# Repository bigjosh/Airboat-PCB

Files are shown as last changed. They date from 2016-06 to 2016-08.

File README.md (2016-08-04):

Airboat
=======

Firmware and board files for Dame Products Airboat. More product info here...

http://www.dameproducts.com/

Note that this is a fork of the original EVA V2 design which is available here...

https://github.com/bigjosh/vibe-v2

Changes include....

1. Much smaller form factor.
2. MCU switched to smaller ATTINY25/45/85 device.
3. Battery charge controller switched to smaller MCP73832 device.

User Interface
--------------

###Transit Lockout Mode
Device ships in Transit Lockout Mode to prevent inadvertently turning on while in transit. In this mode, the button is completely disconnected and non-functional. To escape from Transit Lockout Mode into normal operating mode, you must connect the unit to the charger.

You can put the device back into Transit Lockout Mode by holding the button down for longer than 10 seconds. During the countdown, the green LED will briefly flash once per second.

After the countdown expires, the  green LED will fade out to indicate that Transit Lockout Mode has been activated.

Note that putting the device into transit lockout mode will reset the speed settings to their factory default values. Considering that there (currently) is no way to change these settings in a production unit, this is probably a null feature, but could be useful if somehow the settings ever get corrupted in a field unit.  

Note: this mode also protects the unit from over discharging the battery in case the button gets stuck down because something is continuously pressing on it.

###Normal Operating Mode
Device is normally in a low-power off state.

A long button press (~0.25 sec) goes straight to off state from any speed. 

A short button press steps to the next speed setting upon button release. There are 3 speed settings (low, medium, high) and a 4th button press returns to off state.

When the battery gets low, the motor turns off and the red LED lights for about 1 second. Subsequent button pushes blink the red LED again to indicate that there is not enough power to turn on. Note that Lithium Polymer batteries recover some voltage while resting, so it is possible to briefly turn the unit back on even after it has automatically turned off from low battery. Doing this repeatedly will lead to shorter and shorter on times until eventually the battery is too depleted to have any recovery left.

Because the battery has reduced voltage under load, there are different cutoff voltages for initial turn on and continuing operation. The battery must be at least 3.3 volts for the motor to start, but once started it will continue to run until the battery drops to 3.1 volts. 

For user feedback, both LEDs light for about 250ms when the button is pressed. If the button is held down, it the  LEDs will flash for 100ms every second until either the button is released or <a href="#transit-lockout-mode">Transit Lockout Mode</a> is activated.  

The green LED also indicates charger status: 

* Off means no charger connected
* On solid, full brightness means charger is connected and battery is fully recharged (LED blinks for 62ms once every 8 seconds)
* Slow pulse (1Hz) means charging

Motor is always off while charger connected. Button state is ignored while the charger is connected.

Test Mode
---------
On initial power-up, the devices enters a test mode...

1. You should see the LEDs alternate blinking red and green at about 10Hz. This lets you visually verify both LEDs are working. 
  1. If you don't see anything on power-up, then either both LEDs are broken or there is some worse problem.
  2. If you see a single LED blinking on and off at 10Hz, then the other LED is bad.
  3. If you see the while LED on at 50%, then you probably have a stuck button. 

2. Press the button. The green LED should light solid at 50% brightness for as long as you hold down the button. The green LED should go out when you release the button.
  1. If the LEDs continue to alternate flash after you push the button, then you probably have a bad button or bad connection from the board to the button. 
  2. If the green LED stays lit at 50% brightness after you release the button, then you probably have a stuck button.

If the button is pressed during initial power-up, then the normal test mode red/green blinking is skipped (because this is typically terminated by a button press).

Both of the above LED indications time out after about 30 seconds to avoid killing the battery. If the button stays down past the timeout, the the unit will eventually enter <a href="#transit-lockout-mode"Transit Lockout Mode</a>.

If the LEDs seem to be flashing much faster than 10Hz (like pretty much just see orange) and the timeout seems to be much faster than 30 seconds (like 5 seconds), then it is likely that the fuses on the chip that control the clock speed have not been programmed correctly.  

Test mode only happens on initial power up. The board is very low power so it can continue to operate off the residual charge in the capacitor for a long time (days-months) after the battery is disconnected. Because of this, you must follow this procedure to re-enter test mode once the device has been powered up (it is not enough just to remove the battery and replace it)... 

1. disconnect all power (unplug the battery, unplug charger)
2. push and hold the button for a second to exhaust all the residual power from the capacitors
3. reconnect power and test mode should start again

Features
--------
* Current draw of <0.1uA when idle, so battery self-drain is likely the limiting factor for maximum off time.
* Zero latency button debounce.
* Motor output power is scaled to battery voltage so motor speed stays constant though battery discharge (at least until there is not enough voltage left to maintain speed). 
* Code size of about 1.5K easily fits into cheap parts. 
* A full processor WatchDog reset is executed every time the motor is turned off or the charger is unplugged. This hopefully makes the unit more robust to failures.

Connections
-----------
The specified battery is a 160mAh Polymer Li-ion. Positive battery wire connects to pad closest to the LED/jack end  of the board.

The specified motor is a vibration type nominally rated for 130mA at 3V.

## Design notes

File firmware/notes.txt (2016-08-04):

Programming Instructions for Dame Products AIRBOAT PCB
======================================================

This release is tailored  for an ATTINY25 part. 

Both FLASH and FUSE memory must be programmed for correct operation. 

FLASH memory MUST be programmed using the attached Airboard.firmware.hex file in Intel HEX format.

FUSE memory MUST be programmed with the settings described in the FUSES.TXT file. 

###

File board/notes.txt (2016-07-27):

1. Fabrication

Double sided, 2-layer PCB. 

L-shaped as shown in outline layer.

Board total thickness of 1mm,  ENIG finish.

No impedance control.

1oz copper, FR4 or FR1 material.

Green solder mask. Other color may be substituted. 

Optional White Legend specified in silk layers. Other color may be substituted, or silk layers omitted. 

Minimal clearance size: 7 mils. Minimal trace width: 8 mils. 

Vias may be tented. 

The shrink or swell on the included paste and mask layers should be adjusted depending on stencil type and process.

This board is intended to be broken into 2 sub-boards later. The gerber layer named "top-vgrove" contains a single linear 1mm wide v-grove 
intended to separate the two sub-boards with the resulting dimensions of 23mm x 16mm and 4.5mm x 14mm.

2. Assembly

Reflow soldering for SMD parts.

Board contains 4 sets of 2 pads each labeled BUT, MOT, BAT, and BUT2. These pads are connection points for jumper wires. 

Each of the two pads on BUT will be connected to each of the two pads on BUT2 with 30mm (tip-to-tip) segments of AWG 30 insulated jumper wire. 
Wires must be connected so that when the smaller board can be detached, rotated, and moved such that the wires are straight, parallel, and not crossing. 
See attached wire assembly drawing for details. 

The pads on MOT and BAT will be manually soldered later. 

3. Part orientation

Dot on silkscreen layer indicates pin 1 for parts Q1, D2, and M1.

Notch on silkscreen layer indicates side for pin 1 for part U1.

Parts F1, C4, R1, S1,and R3 may be oriented in any direction. 

LED L1 must be placed with (1) the diffusion bubble pointed towards the closes board edge, and (2) the green dot cathode mark on the left side when
viewed from the rear of the part. Refer to photos in the "/Orientation Photos" directory of the file package. 

4. Firmware programming

Part U1 requires both fuse and flash programming. 

The IC can be programmed directly by the distributor or onsite using a bulk programmer. 

The IC can also be programmed or re-programmed after assembly using an SOIC8 programming clip and USBASP programmer. More information upon request.

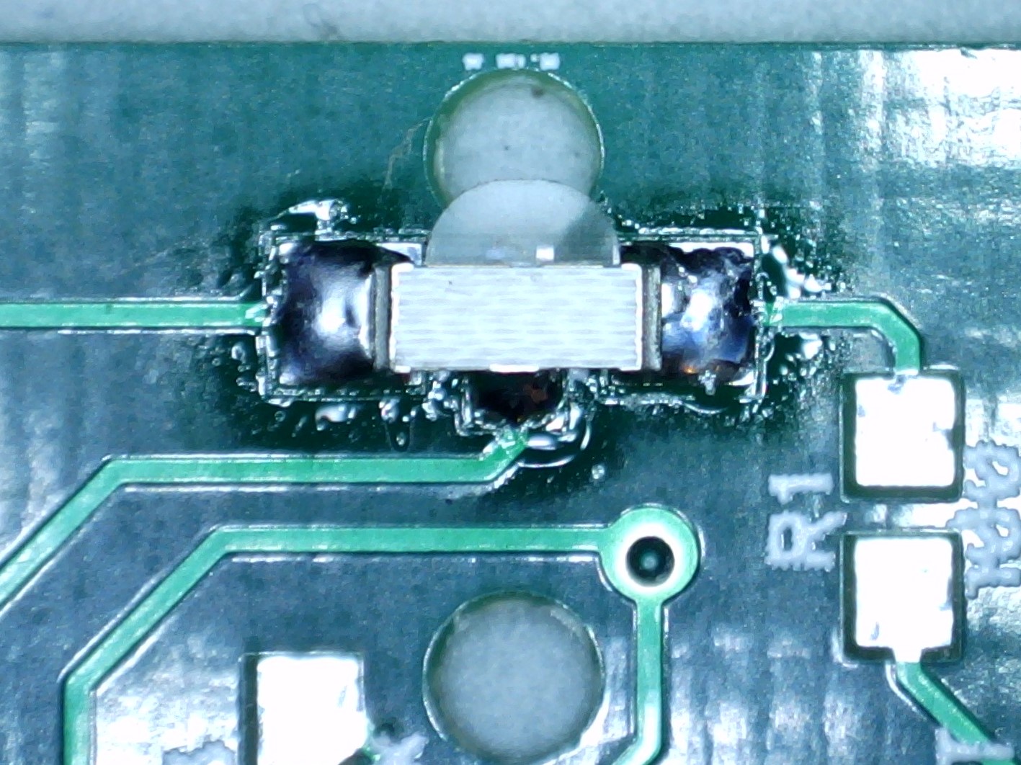
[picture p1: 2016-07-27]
board/Orientation Photos/L1 - Top view.jpg

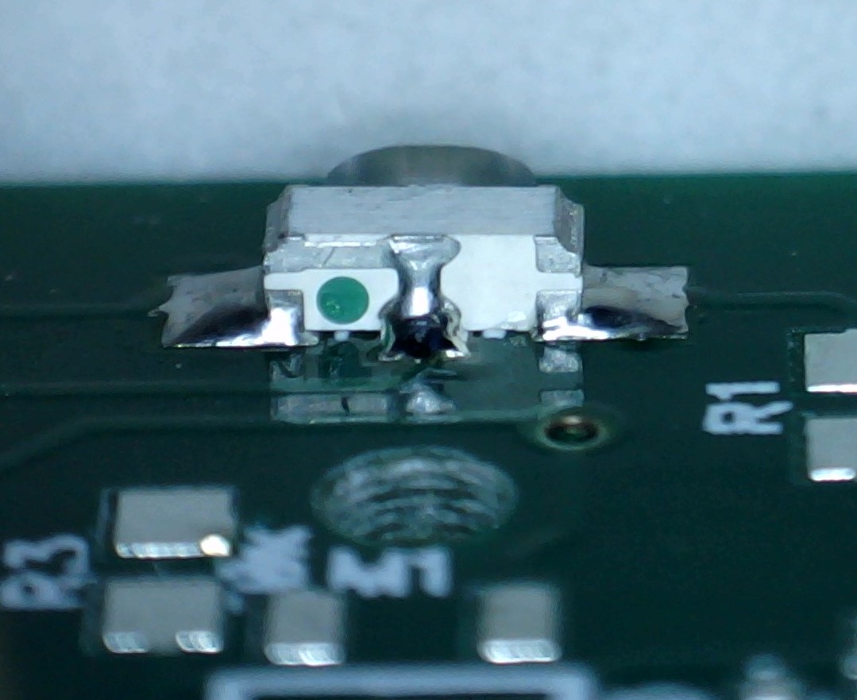
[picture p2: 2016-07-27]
board/Orientation Photos/L1 - Rear view.jpg

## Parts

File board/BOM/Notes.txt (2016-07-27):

The BOM file is in Digikey CSV format. 

Substitutions
=============
None of the parts are critical.

The resistors and capacitors can be substiuted for any suitable part within at least +/- 20% of value.

F1 can be repalced with any suitable 0603 fuse with minium 250mA blow current. It can also be repalced with an SMD 0.0OHM JUMPER 1/10W 0603, 
but doing so would reduce overcurrent and overvoltage protections. 

U1 can be substiutied with any part in the line, although changing to a ATTINY45 or ATTINY85 will require a recompile of the 
firmware, and changing to a different package will require changes to the footprint on the PCB.

L1 can be replace with different color pair part that has correct polarty and fits the pads.

M1 can be replaced with the same part in a different SOIC package, although this would require changes to the footprint on the PCB. 
This part has a variant MCP73831 that should *not* be substituted because it could potentially increase idle power usage.

Q1 can be replaced with any suitable N-Chan SOT23 MOSFET with the same pinout and minimum 30V/200mA. It must also have low leakage current 
becuase any leakage will contribute to idle power usage.

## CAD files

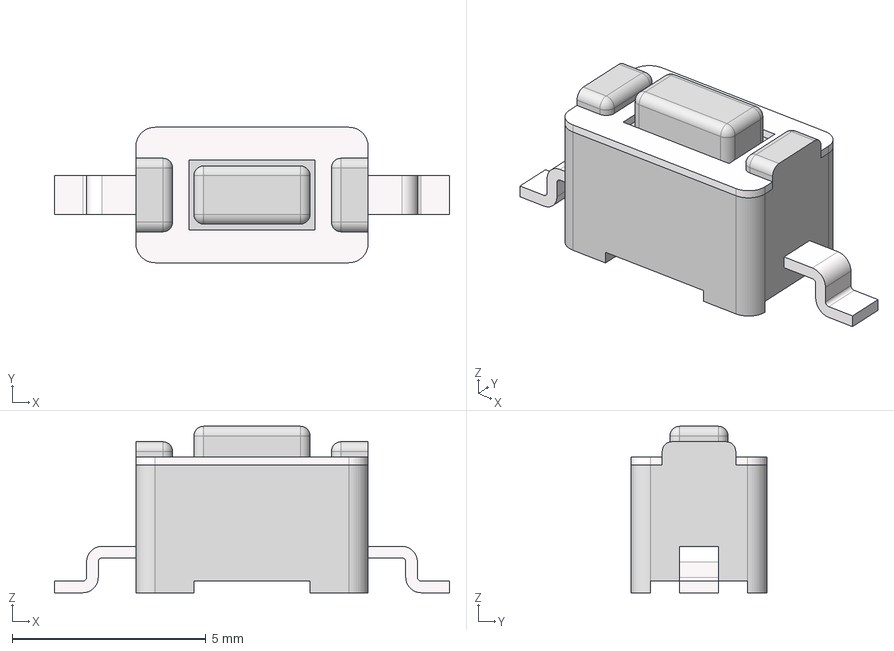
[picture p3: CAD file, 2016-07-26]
board/Design Files/3D Models/TL3302AFXXXQG.stp
10.2 x 3.50 x 4.30 mm
TL1107-3302 BODY
TL1107-3302 COVER
TL3302 G TERM x 2
TL1107-3302 A ACTUATOR

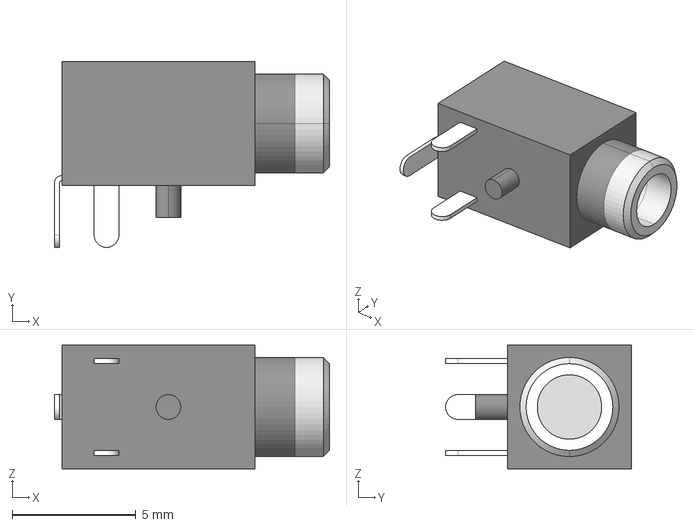
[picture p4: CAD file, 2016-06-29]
board/Design Files/3D Models/mj1-2503a.stp
11.1 x 7.50 x 5.00 mm

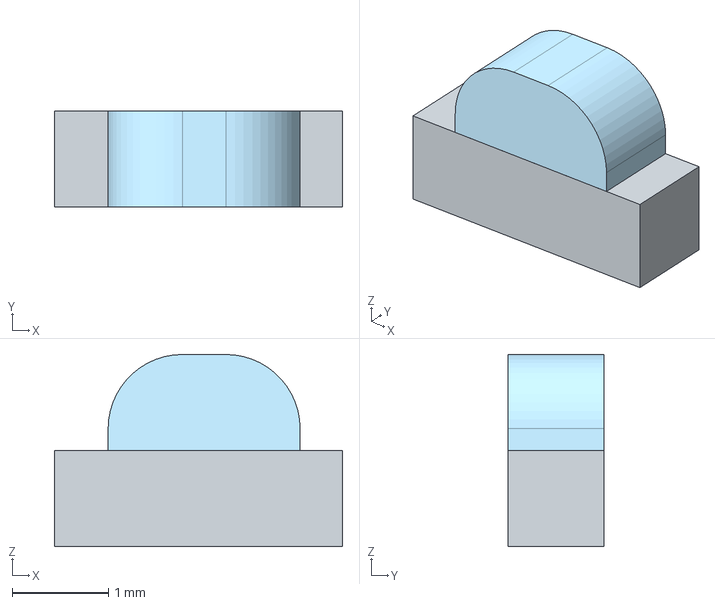
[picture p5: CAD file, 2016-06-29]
board/Design Files/3D Models/Bicolor LED.step
3.00 x 1.00 x 2.00 mm

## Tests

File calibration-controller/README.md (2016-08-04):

The Calibration Remote Controller connects to an AIRBOAT though the charging jack and lets you precisely adjust the motor control and LED parameters to find the best values. 

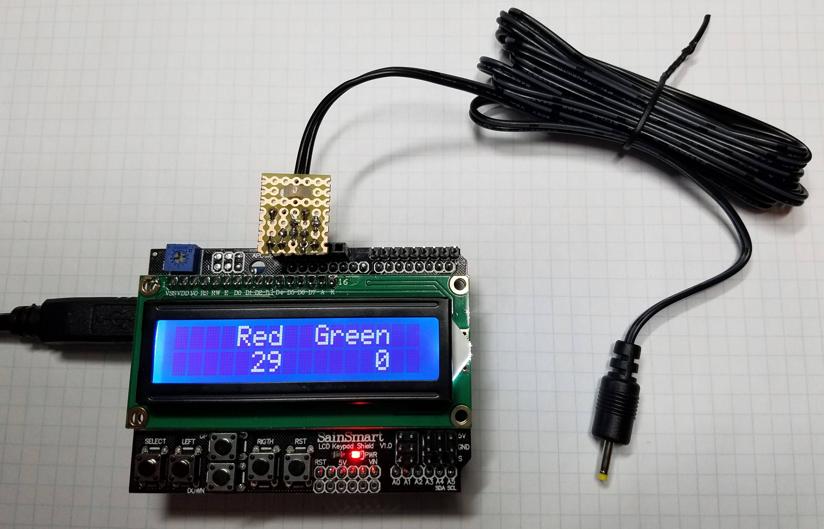
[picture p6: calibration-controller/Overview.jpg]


#Quick Start

1. You'll need an Airboat board specifically programmed with the calibration controller function enabled in the firmware. You enable it with `#define CALIBRATION` in the source code. 
2. Since the shell and overmold affect the way the motor vibrates and the LEDs look, you should build the board into an assembled unit before tweaking.
3. Connect the Controller USB cable to a computer or power outlet. 
4. Insert the plug from the controller into your special Airboat unit.
5. Push the button on the Airboat to turn it on and select the 1st speed setting. For best results, Airboat should [always be on](#constraints) when changing settings on the controller. 
6. Use the left and right buttons to change the `top` value and the up and down buttons to change the `duty` value. Hold them down to scroll faster. Note that the controller only sends updates when a value changes, so make sure you change both values (click up then down) to update them into the unit. 
7. When you find the exact perfect values, write them down! While the new values are stored in the unit, you will not have any way to see the actual numbers once you disconnect/turn off the controller.
8. You can switch to different speeds on the unit and then use the controller to adjust those speeds. This makes it possible to program a unit with customer speeds for all three settings.
8. Press `select` to go into LED mode.
9. Use the buttons to change the mixture of the red and green LEDs to make nice looking colors, then write down the combinations you like. 
 
#Speed Parameters

Each speed setting has two parameters – the `DUTY` and the `TOP`. 

The `DUTY` controls what percentage of the time the motor is getting power. It ranges from 0 (completely off) to 255 (always on). So, a value of about 128 means that the motor will be getting power about ½ the time. The motor is only rated for 3 volts but the battery is nominally 4.2 volts, so best not to run with `DUTY` set higher than about 186 for too long or the motor might over heat. 

>NOTE: We could someday add a “turbo” mode that severely over powers the motor for short bursts as long as the busts are short enough that the motor doesn’t get too hot. 

`TOP` is the number of counts per on/off cycle where a count is 1/128000th of a second. This selects the frequency at which the motor is turned on and off and ranges from about 2Hz to 64KHz. Note that the steps between available frequencies are larger for lower frequencies.

To normalize the human readable `TOP` value on the controller screen to the computer readable `TOP` and `PRESCALE` values to type into the source code, you can use the included calculator tool here...

http://htmlpreview.github.io/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

(or open the HTML file directly from you local hard drive)

>NOTE: As you scan though the `TOP` values you will find some that are at frequencies that your ear can hear. We can someday use this to make the motor make beeps and sounds. 

#Usage

To use the Remote Control, plug it into an AIRBOAT with the calibration firmware enabled though the power port. 

You can then use the Remote to update the speed settings.

|Button|MOTOR Mode|LED Mode|
|-|-|-|
|LEFT & RIGHT|TOP|Red|
|UP & DOWN|DUTY|Green

Holding a button down will scroll the value with acceleration for big changes. 

Once you find values that you like for a given speed, write down the two numbers since once you switch to another speed or unplug the Remote, there is no easy way to get them back. 

#Theory of Operation

The controller communicates to the attached AIRBOAT by turning the power supplied though the jack on and off. Each time the power is on, the battery charger chip indicates a "charge in progress", so by turning the power on and off rapidly the controller can send bits to the AIRBOAT.

## Data Format

### Signals

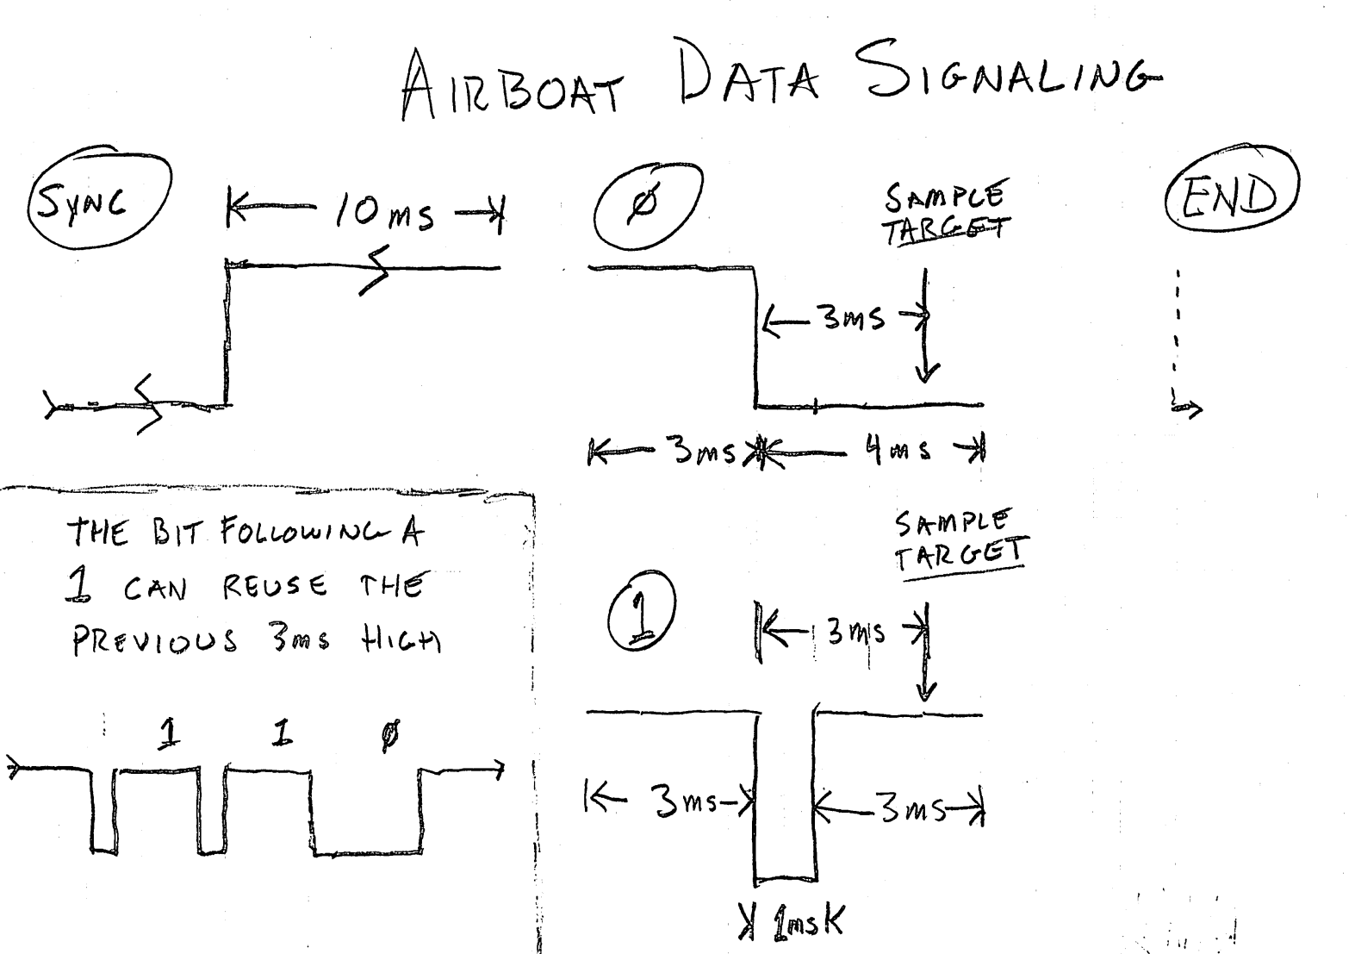
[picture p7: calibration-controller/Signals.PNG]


Commands are sent as 16 bit long packets.

A packet always starts with the power off. 

Each packet starts with 10ms of on time. This give the AIRBOAT time to get ready for the first sync pulse. 

Each bit starts with sync pulse that is 3ms of on, followed by a 1ms off. 

The data value is sampled 3ms after the falling edge of the sync pulse.  Timing is based off the falling edge of this sync pulse because the charger reacts quickly to falling voltage but slowly to rising voltage.

To send a 1 bit, the power is left on for 3ms after the sync pulse. 

To send a 0 bit, the power is left on for 3ms after the sync pulse. 

The packet always terminates with the power off. 

Bytes are sent most significant bit first. 

###Constraints

If the power is on for more than about 1.5ms and the battery is fully charged, then the COP will turn off even though power is still applied. This can be avoided but only sending data when the unit is on since the drain of the motor will prevent the charger from detecting EOC.  

Because there is a filtering capacitor across the power jack, it takes about 1ms for the power voltage to drop to 0V after we stop supping power. The COP stops when it hits ~4.5 volts, which happens pretty quickly. 

### Protocol

A command consists of 16 bits.

	// Command format (bits, MSB first)  ccc aaaa bbbbbbbb p
	//
	// c=command code
	// a,b variables
	// p=parity (all bits including parity add up to 0)

	// Commands:
	//
	// 00: NA
	// 01: Set red LED to brightness b
	// 02: Set green LED to brightness b
	// 03: Set motor normalized duty to b
	// 04: Set motor prescaller to a and top to b
	// 05: Reset motor speed steps to factory default values

#Construction

The controller is actually just an Arduino Uno with an [LED Keypad Shield](http://www.dfrobot.com/wiki/index.php?title=Arduino_LCD_KeyPad_Shield_%28SKU:_DFR0009%29). 

The data is output on digital pin D0 because this happens to be in a handly location on the top header of the LCD board- along with Vcc and ground. 

Because the pin can not output enough current to keep  CIP active for long, we use a transistor to switch the full 5V power coming from the Arduino header. It looks like this...

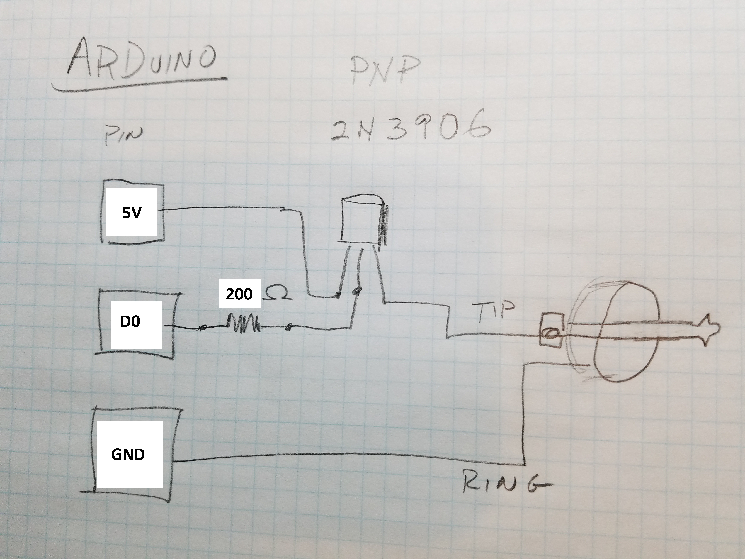
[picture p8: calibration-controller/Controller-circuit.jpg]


The circuit fits nicely on a little perfboard like this...

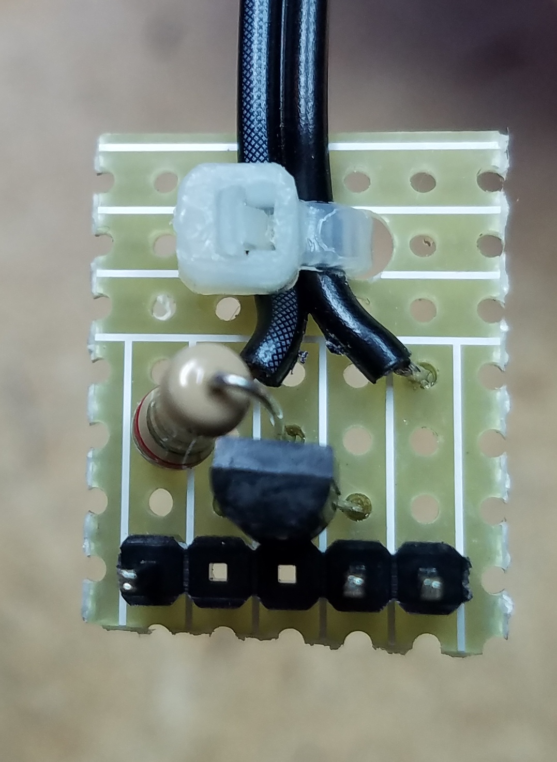
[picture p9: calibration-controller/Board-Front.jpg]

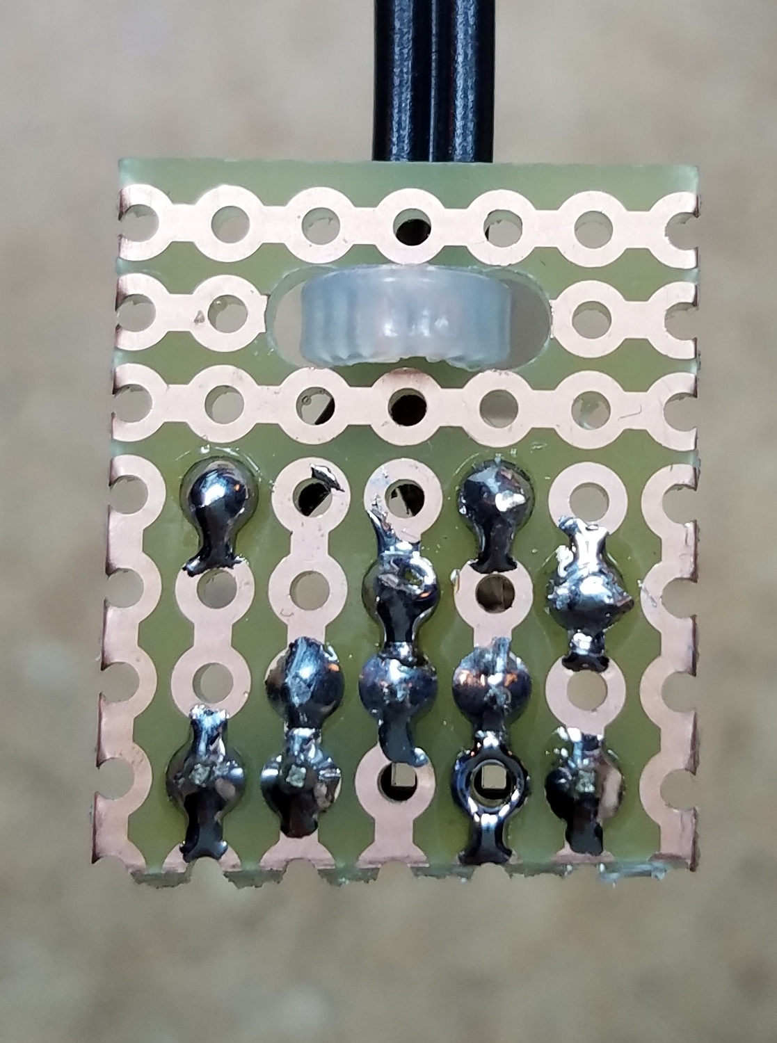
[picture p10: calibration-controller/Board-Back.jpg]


The perfboard installs left justified onto [header J8 on the LCD board](0044.lcd-keypad-shield-datasheet.pdf). If constructed as above, the components should be facing down. 

#Future Directions

It would not be hard to integrate the controller functions into the mainline firmware and then make a cute little fob that users could plug into their Airboat to make custom settings. 

This would also open the doors to DYI'ers who wanted to remote control the unit using their own Arduino.  

Might also be nice to add support for patterns rather than just simple on/off PWM.

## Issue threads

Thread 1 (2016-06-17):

Resistor R1 is unnecessary for production

bigjosh, 2016-06-17:
This resistor allows in-circuit flash reprogramming - without it the LEDs prevent the programming voltages from getting high enough. Once the firmware is stable, this resistor can be removed and the value for `LED_DIM_FACTOR` can be updated to compensate.

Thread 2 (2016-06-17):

Motor PWM may be too slow

bigjosh, 2016-06-17:
The ATTINY currently runs with clock/8 set, so the ultimate clock frequency is 1MHz. This is done to fall below the FCC Part 15 threshold.

At this clock, the motor PWM frequency comes out to 4KHz, which is audible.

This could be fixed by....

1. Using the faster PLL clock for motor PWM. I don't think this would cause any FCC problems becuase the output signal is still well below the threshold, but should be checked.

2. Using a lower `TOP`. This would increase frequency at the cost of reduced resolution.

bigjosh, 2016-07-26:
Currently running clock at 128Khz and the motor pwm is so low as to be inaudible. Lower freq even seems to give better vibration. Would love to do long-term endurance testing to see if effects motor life.

Closed 2016-07-26.

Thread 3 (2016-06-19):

Over-voltage protection

bigjosh, 2016-06-19:
So far only a single EVA has come back with overvoltage damage due to an improper charger, and that unit was shipped without a matching charger. But it is not clear is Airboat would be more or less susceptible to improper chargers because it uses a 2.5mm audio jack for charging. There certainly seems like more opportunities for people to ruin other devices by plugging the Airboat charger into audio jacks....

Over-voltage protect would be straightforward to add by putting a ~6V zener across the power jack inputs. A ~200mA fuse in series would blow before the Zener got hot and would also protect from over-current, possible from hard shorts on the board (we did see one EVA with a loose screw that shorted the board).

bigjosh, 2016-07-26:
Added 250mA fuse which will prevent some faults, but could also add the zener for better protect but will require testing.

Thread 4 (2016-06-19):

Switch to iPod-style 2.5mm charger port?

bigjosh, 2016-06-19:
The 4 conductor 2.5mm charger seems to be more common than the 2 conductor one we used, so it would be easy to find off the shelf  cables.

bigjosh, 2016-07-26:
Switched to normal power jack.

Closed 2016-07-26.

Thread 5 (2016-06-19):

Red LED comes on intermittently when button pressed/motor activated

bigjosh, 2016-06-19:
This is a real unexplained issue. Maybe some interaction on the silicon between the 2 timer units?

bigjosh, 2016-06-21:
Turned out to be the workaround for the silicon errata. Removed the workaround but hopefully should never be a problem with new parts.

Closed 2016-06-21.

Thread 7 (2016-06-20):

Power jack tabs currently have hole footprints rather than slots

bigjosh, 2016-06-20:
This is because (1) Otherplan can not current cut slots for no good reason, (2) Sunstone charges extra for slots.

Current footprints work fine, but might want to switch back before production.

DameRebeca, 2016-06-29:
Work fine - then okay with me.  Suggest, no need to change back, leave as is.

bigjosh, 2016-06-29:
They do work fine, but we had a factory who really didn't like them. Once we get a beta board, I'll probably switch back to slots just to avoid any conflict.

bigjosh, 2016-07-26:
Power jack replace with SMT version so no more holes.

Closed 2016-07-26.

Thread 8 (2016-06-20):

Power jack shorts on insertion

bigjosh, 2016-06-20:
2.5mm audio jacks are not good for power. If you insert at the wrong angle, it is not hard to short the tip and ring together, which smokes the protection diode on the current version. Not good. Also has to potential to short the power supply or USB adapter.

bigjosh, 2016-07-26:
Switched back to power jack that physically con not short. New diode-array also puts an extra diode in the short path.

Closed 2016-07-26.

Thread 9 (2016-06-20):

Button aux board too short for current button part footprints

bigjosh, 2016-06-20:
Either the board will need to get longer, or we'll have to use a part with a shorter footprint like a J-lead, although those make inspection hard.

bigjosh, 2016-07-26:
Increased button board size and used standard footprint.

Closed 2016-07-26.

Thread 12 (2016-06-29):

No way to detect End Of Charge

bigjosh, 2016-06-29:
The current battery controller chip does not provide an end-of-charge status.

Previous we determined state by checking for a high Vcc voltage. If we saw that a charger was attached, but we did not see a charge-in-progress status, then we knew we were at end-of-charge (or some kind of battery error).

We had to remove the Vcc feedback because of the possibility of shorts when the audio plug was inserted. Hopefully we can get it back when we switch to a safe power jack.

bigjosh, 2016-07-26:
New diode-array feeds jack power directly to U1 Vcc so it can detect EOC when Vcc is greater than possible by battery (>4.3V) and there is not currently CIP.

Closed 2016-07-26.

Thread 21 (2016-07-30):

Test idle power

bigjosh, 2016-07-30:
Enough changes that this need to be tested again before production to make sure no leakage leaked into the design.

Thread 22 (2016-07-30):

Production Battery Datasheets

bigjosh, 2016-07-30:
The charging and discharging parameters should be optimized for the actual exact battery for best run-time and lifetime.

This could involve changing...

1. The low battery cut-off voltage in the firmware
2. Picking a different variant of the MCP charger chip with a lower termination current
3. Changing the PROG resistor to change the charge rate

bigjosh, 2016-08-24:
This new datasheet says you can fast charge at up to 1C, which is 150mA. We limit our changing rate to 100mA though PROG, so the current design is well within these constraints. Issue closed!

[DPD31-KPL352028-170mAh+1S1P+板（G3J+8205+ BH1S0415002 +UL1571-28#160805A2.pdf](https://github.com/bigjosh/Airboat-PCB/files/435364/DPD31-KPL352028-170mAh.1S1P.G3J.8205.BH1S0415002.UL1571-28.160805A2.pdf)

Closed 2016-08-24.

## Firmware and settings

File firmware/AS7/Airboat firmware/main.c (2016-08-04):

/*
 * main.c
 *
 * Created: 6/13/2016 12:25:41 PM
 *  Author: josh.com
 *  Based on Vibe V2 firmware
 */ 


/*

 Note to gentle reader: 
 The target product is encased in a silicone overmold, so there is no practical way to do a "battery pull" reset 
 on the circuit in case of a latch-up. There was also no good way to add a hardware reset button to the product.
 
 Therefore, this is a defensive style designed to keep running and self correct.
 The program is designed to completely reset the MPU every time the motor turns off or the power charger
 is unplugged or the button is held down for too long.
  
 -josh
 
*/



/* 
	FUSE SETTINGS:
	
	All default except for 
	
	CKDIV8 = No set (do not divide clock)
	SUT_CKSEL = WDOSC_128KHZ_6CK_14CK_0MS (Internal 128Khz osc)
	
	We run on the super slow clock to avoid triggering FCC Part 15 compliance.
	
	Note that once these fuses are set, you need to use a 32Khz programming clock or slow to communicate with the chip. 
*/



// CPU speed in Hz. Needed for timing functions.
// This is the default fuse setting and works fine for PWM frequencies up to about 10Khz (1% lowest duty), or 100KHz (10% lowest duty). 
// This suits the current speed settings, but a high clock might be needed for higher PWM frequencies

#define F_CPU 128000						// Name used by delay.h		
											// Note that there is a hardcoded delay look in readbyte() that needs to be adjusted if this changes!
											// The ADC prescaler in readVccVoltage(0 also depends on the system clock.

#define CYCLES_PER_S F_CPU					// Better name									

#define CYCLES_PER_MS (F_CPU/1000UL)		// More convenient unit

#define US_PER_S	1000000					

// This will enable connection to a calibration controller though the power jack.
// This suppresses the charging feedback, and also stops the motor from turning off if charger is connected,
// so this is for in-house testing only! Boards with this firmware are NOT FCC Part 15 exempt!

//#define CALIBRATION


// ** Outputs

#define WHITE_LED_PORT PORTB
#define WHITE_LED_DDR DDRB
#define WHITE_LED_BIT 0

#define RED_LED_PORT PORTB
#define RED_LED_DDR DDRB
#define RED_LED_BIT 1


// ** Inputs

// * Button

#define BUTTON_PORT PORTB
#define BUTTON_PIN	PINB
#define BUTTON_DDR  DDRB
#define BUTTON_BIT	3
#define BUTTON_INT	PCINT3

// Is button currently pressed? Pin has a pull-up connected to ground though button, so a down reads as 0 on the pin. 
// (Compiles down to a single SBIC instruction)

#define BUTTON_STATE_DOWN()	((BUTTON_PIN & _BV(BUTTON_BIT))==0)

// * CIP

// CIP is the charge-in-progress signal. It s active LOW when battery is charging.
// High when battery is full or when no charger is attached. 
// It is connected to the STAT line from the battery controller
// The STAT signal is open collector, so we must be pull up this line

#define CIP_PORT PORTB
#define CIP_PIN  PINB
#define CIP_DDR	 DDRB
#define CIP_BIT 2
#define CIP_INT PCINT2

// CIP is pulled LOW by battery charger to indicate Charge In Progress
// (Compiles down to a single SBIC instruction)

#define CIP_STATE_ACTIVE()		((CIP_PIN & _BV(CIP_BIT))==0)


// CIP as receive only serial port
// Can can read data send at quickly switched charger voltage by looking at the CIP pin 
// Speed is limited by out timing precision and also how fast the signal can rise and fall
// Pulling the charger jack low for 0 bits makes the signal fall faster

#define SERIAL_BPS			(1200)					// Run nice and slow at 1200 baud
#define SERIAL_BITTIME_US	(1000000UL/SERIAL_BPS)


// * Battery Voltage

// We use a trick to read the battery voltage from the Vcc pin...
// https://wp.josh.com/2014/11/06/battery-fuel-guage-with-zero-parts-and-zero-pins-on-avr/

// Different cutoffs because the drain of the motor on the battery lowers the voltage, which will recover when the 
// motor is turned off

#define LOW_BATTERY_VOLTS_WARMx10	(31-03)		// Low battery cutoff while running, 3.1 volts for battery less the 0.3V diode drop
#define LOW_BATTERY_VOLTS_COLDx10	(33-03)		// Low battery cutoff to turn on   , 3.3 volts for battery less the 0.3V diode drop

#define CHARGER_VOLTAGE_THRESHOLD   (43)		// If we see this voltage or more on Vcc, then we are connected to a charger. One shottkey diode drop between charger and MCU. 


// ** UI

#define BUTTON_DEBOUNCE_TIME_MS 25			// How long to wait for a button press debounce

#define JACK_DEBOUNCE_TIME_MS 100			// How long to wait for a battery charger state change debounce

#define BUTTON_LONG_PRESS_MS 500			// How long to hold down button to be considered a long press rather than a push
											// Long press immediately turns off motor without needing to cycle though remaining speeds

#define BUTTON_TRANSIT_TIMEOUT_S (10)		// How long does the button need to be held down for to enter transit lockout mode?


#define LOW_BATTERY_LED_ONTIME_MS (1000)	// We show low battery by flashing red LED this long before shutting down.
#define LOW_BATTERY_LED_BRIGHTNESS_PCT (100)// We show low battery by flashing red LED this long before shutting down (percent,100=full brightness).

#define BUTTON_FEEDBACK_BRIGHTNESS_PCT (100)// We blink the LED when the button is pressed. Use this brightness (percent,100=full brightness).

#define REBOOT() 	{wdt_enable( WDTO_30MS);while(1);}		// Use watchdog to reset MPU. Note that this is sometimes used to also debounce button so probably not quicker than 32ms
	
#define PCT_TO_255(x) ((x*100)/255)			// Convert a human friendly percent to 0-255 scale

#include <avr/io.h>
#include <avr/fuse.h>
#include <util/delay.h>
#include <avr/power.h>
#include <avr/sleep.h>
#include <avr/interrupt.h>
#include <avr/eeprom.h>
#include <avr/wdt.h>
#include <avr/pgmspace.h>


// These fuse settings will appear in the .ELF output file

FUSES =
{
    (FUSE_CKSEL0 & FUSE_CKSEL1 & FUSE_CKSEL3 & FUSE_SUT0 & FUSE_SUT1),  // L:   128KHz internal RC oscillator, 0ms delay (wow, that was counter intuitive which bits are 0 or 1!)
    FUSE_SPIEN ,					                                    // H:   Needed to allow reprogramming
    EFUSE_DEFAULT                                                       // E:   Default 
};



static void initButton() {
	BUTTON_PORT|=_BV(BUTTON_BIT); // Enable button pull-up
	
}		

static void disableButton() {
	BUTTON_PORT &= ~_BV(BUTTON_BIT); // Disable button pull-up		
}

static void initCIP() {
	
	// Battery Charger status pin setup
	
	CIP_PORT |= _BV( CIP_BIT);				
	// Activate pull-up, prevent floating input
	// This input is connected to an open-drain on the battery charging chip. It pulls low during charging. 
	// If the CIP is actually low, that means we are getting power from the charger so we don't need to worry about
	// draining the battery.	
}

// MOTOR FUNCTIONS
// ===============
// Note that register values are hard coded rather than #defined because they 
// can not just be moved around. They depend on the Timer hardware of the specific chip/pin. 

// Motor is controller by an N-MOSFET which is connected to pin OC1B. 1 output turns motor on, 0 is off. 
									
// Turn the motor completely off- disconnects from PWM generator

static void motorOff(void) {

		
	GTCCR = 0;		// "Timer/Counter Comparator B disconnected from output pin OC1B"	
					// Will revert back to PORT value, which we always keep at zero.
		
}

// Initialize the motor pin. Sets to output mode, which will drive pin LOW.
// Call this as soon as possible after reset to keep the mosfet from floating and turning on the motor.

static void initMotor() {
	
						// On ATTINYx5, OC1B happens to be an alternate function on pin PB4. 
	DDRB |= _BV(4);		// Set pin to output mode. It will already be low because IO ports default to 0 on reset.
	
}

// Set motor PWM

// match sets the duty cycle and should be between 0 and top. 0=completely off, top=full on. 
// top sets the frequency where PWM frequency = F_CPU/top. The minimum resolution allowed is 2-bit (top set to 0x0003).

// Note: also uses OCR1C for TOP function.
// Note: resets all used registers each time from scratch for safety from glitches. This is probably  unnecessary...
// http://electronics.stackexchange.com/questions/139575/how-often-do-avrs-actually-glitch-and-need-a-watch-dog-reset-in-the-real-world/144318


static void setMotorPWM( uint8_t match , uint8_t top , uint8_t prescale ) {
			
	if (match==0) {			// Special case this because the PWM generator still generates a pulse at 0 duty cycle
							// "If the OCR1x is set equal to BOTTOM (0x0000) the output will be a narrow spike for each TOP+1 timer clock cycle."
		
		motorOff();
		
	} else {
		
		//        01234567
		//        ========
		//        1         CTC1            1="When the CTC1 control bit is set (one), Timer/Counter1 is reset to $00 in the CPU clock cycle after a compare match with OCR1C register value."
		//            pppp	CS1[3:0]		prescaler
		
		TCCR1 = _BV(CTC1) | (prescale & ( _BV(CS10)|_BV(CS11)|_BV(CS12)|_BV(CS13)) );
		
		//         1		 PWM1B			1 = Enable PWM B
		//          11       COM1B			11 = Set the OC1B output line on compare match
		GTCCR = 0b011100000;		
		
		OCR1B = match;		
		
		OCR1C = top;	// Counter top value - resets to zero when we get here
		
		// Note that there is a silicon bug that might make this not work on older parts:
		// http://electronics.stackexchange.com/questions/97596/attiny85-pwm-why-does-com1a0-need-to-be-set-before-pwm-b-will-work
												
	}
	
}


// Returns the current Vcc voltage as a fixed point number with 1 implied decimal places, i.e.
// 50 = 5 volts, 25 = 2.5 volts,  19 = 1.9 volts
//
// More info on this technique:
// https://wp.josh.com/2014/11/06/battery-fuel-guage-with-zero-parts-and-zero-pins-on-avr/
//
// On each reading we: enable the ADC, take the measurement, and then disable the ADC for power savings.
// This takes >1ms becuase the internal reference voltage must stabilize each time the ADC is enabled.
// For faster readings, you could initialize once, and then take multiple fast readings, just make sure to
// disable the ADC before going to sleep so you don't waste power. 

static uint8_t readVccVoltage(void) {
	
	
	/*
	By default, the successive approximation circuitry requires an input clock frequency between 50
	kHz and 200 kHz to get maximum resolution.
	*/	
				
	// Enable ADC, no prescaler so we will run ADC at 125kHz. 
	
	ADCSRA = _BV(ADEN);


	// Select ADC inputs
	// bit    76543210
	// REFS = 00 0     = Vcc used as Vref
	// ADLAR=   0	   = Reading is right adjusted (only 8 most significant bits)
	// MUX  =     1100 = Single ended, 1.1V (Internal Ref) as Vin (Called just Vbg in the datasheets- presumably for Band Gap)
	
	ADMUX = 0b00001100;

	
	/*
		After switching to internal voltage reference the ADC requires a settling time of 1ms before
		measurements are stable. Conversions starting before this may not be reliable. The ADC must
		be enabled during the settling time.
	*/
		
	_delay_ms(1);
				
	
		
	ADCSRA |= _BV(ADSC);				// Start a conversion


	while( ADCSRA & _BV( ADSC) ) ;		// Wait for 1st conversion to be ready...
										//..and ignore the result
						

	/*
		17.6.2 The first conversion after switching voltage source may be inaccurate, and the user is advised to discard this result.
	*/


	ADCSRA |= _BV(ADSC);				// Start a conversion


	while( ADCSRA & _BV( ADSC) ) ;		// Wait for 2nd conversion to be ready...
	
		
	/*
		After the conversion is complete (ADIF is high), the conversion result can be found in the ADC
		Result Registers (ADCL, ADCH).		
		
		When an ADC conversion is complete, the result is found in these two registers.
		When ADCL is read, the ADC Data Register is not updated until ADCH is read.		
	*/
	
	// Note we could have used ADLAR left adjust mode and then only needed to read a single byte here
		
	uint8_t low  = ADCL;
	uint8_t high = ADCH; 
	
	uint16_t adc = (high << 8) | low;		// 0<= result <=1023
			
	// Compute a fixed point with 1 decimal place (i.e. 5v= 50)
	//
	// ADC = (Vin*1024)/Vref
	// ADC = (1.1v * 1024) / Vcc
	
	// Vcc   =  (1.1v * 1024) / ADC
	// Vcc10 = ((1.1v * 1024) / ADC ) * 10			->convert to 1 decimal fixed point
	// Vcc10 = ((11   * 1024) / ADC )				->simplify to all 16-bit integer math
				
	uint8_t vccx10 = (uint8_t) ( (11 * 1024) / adc); 
	
	/*	
		Note that the ADC will not automatically be turned off when entering other sleep modes than Idle
		mode and ADC Noise Reduction mode. The user is advised to write zero to ADEN before entering such
		sleep modes to avoid excessive power consumption.
	*/
	
	ADCSRA &= ~_BV( ADEN );			// Disable ADC to save power
	
	return( vccx10 );
	
}


// Set the motor to run at the specified duty cycle and frequency
// The duty cycle is specified at 4.2 volts as a value 0-255. It is adjusted to scale to the actual voltage. 
// Of course if you specify 100% at 4.2v and only 3.8v is available, then it will just give 100% at the current voltage
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
int main(void)
{
	
	initMotor();				// Initialize the motor port to drive the MOSFET low
								// Do this 1st thing on reset so the MOSFET won't float and accidentally turn on the motor.
		
	// Next, turn on the watchdog before anything else so we have the max protection. 
									
	uint8_t watchDogResetFlag = MCUSR & _BV(WDRF);		/// Save the watchdog flag
	
	MCUSR &= ~ _BV( WDRF );		// Clear the watchdog flag
								// "In safety level 1, WDE is overridden by WDRF in MCUSR...."
								// "This means that WDE is always set when WDRF is set."
								// IF we left this Set, then we could get watchdogged while sleeping
								
	wdt_enable( WDTO_8S );		// Give ourselves 8 seconds before forced reboot			
	


	// TODO: Sort these out so only the proper ones in proper order
	initButton();
	initLEDs();
	enableLEDs();		// DOnt' forget to disable this timer before sleep order else it will use power
	initCIP();			// Enable the CIP pull-up. We will need it from here on out weather we sleep or run.
		
	_delay_us(1);							// Give the pull-ups a second to work	
	
	
				
	if ( !watchDogResetFlag )		{		// Are we coming out of anything except for a WatchDog reset?
		
		// Cold boot, run test mode
				
		// Blink back and forth to show LEDs work and solicit a button press	
		
					
		for(uint8_t i=0;i<100 && !BUTTON_STATE_DOWN(); i++ ) {
			
			setRedLED(255);
			
			for(uint8_t j=0; j<100 && !BUTTON_STATE_DOWN();j++ ) { 
				_delay_ms(1);				
			}
			
			setRedLED(0);
			setGreenLED(255);
			
			for(uint8_t j=0; j<100 && !BUTTON_STATE_DOWN();j++ ) {
				_delay_ms(1);
			}
			
			setGreenLED(0);
					
			wdt_reset();

		}
				
		_delay_ms(BUTTON_DEBOUNCE_TIME_MS);
		
		
		// Set up the initial values for the speedSteps
		
		setSpeedStepDefaults();
		
								
		// TODO: Put more code here for some testing and feedback on initial battery connection at the factory.
		
		// TODO: I think we want 
		
		// TODO: RESET here so we come back up with a clean watchdog? I think that is better so next part is always same state
				
	}

											
	// Ready to begin normal operation!		
	
	if (BUTTON_STATE_DOWN())	{		// Possible stuck button?
		
		// If we get here, either we just finished test mode and the button is still down, in which case
		// we are testing to make sure it goes back up 
		
		// Otherwise we just reset and the button was down when we woke, so likely it is stuck down 
		// and that is what caused the reset. In this case, show the user and then eventually disable the button.
		
		// Each pass of this loop takes ~1 sec.
		
		for( uint16_t t=0; (t < BUTTON_TRANSIT_TIMEOUT_S) && BUTTON_STATE_DOWN(); t++ ) {
			
			
			// To indicate that we are in a stuck-button sequence, we will blink the white LED
			// at 50% brightness, 1Hz, 10% duty cycle. This looks different than other states 
			// and also minimizes battery usage (the LED pulls 10+mA) since we might be doing this
			// for many minutes
			
			// Start with LED off because it looks better when we are coming in from a watchdog
			// reset because the button was held down for more than 8 secs. Otherwise user
			// sees an odd blink pattern. 
			
			
			// Leave the white LED off for 900 ms or until the button goes up
			
			for( uint8_t l=0; l<90 && BUTTON_STATE_DOWN() ; l++) {
				_delay_ms(10);
			}
			
			if (BUTTON_STATE_DOWN()) {												// Suppress brief flash when button released
				setGreenLED( PCT_TO_255(BUTTON_FEEDBACK_BRIGHTNESS_PCT) );
			}
			
			// Leave the white LED on for 100 ms or until the button goes up
			// Could do this as a single _delay_ms(100) but that might feel un-responsive
			
			
			for( uint8_t l=0; l<10 && BUTTON_STATE_DOWN() ; l++) {
				_delay_ms(10);
			}
			
			setLEDsOff();
					
			wdt_reset();		
			
		}
							
		// Debounce the possible button up transition 				
		
		_delay_ms(BUTTON_DEBOUNCE_TIME_MS);		
		
	}
	
	if (BUTTON_STATE_DOWN())	{			// Do we still have a stuck button?


		// Indicate we are entering transit mode with a 1 second fade out of the white LED
		
		_delay_ms(900);			// Don't break the nice visual pattern established durring the lockout sequence
		
		
		uint8_t brightness=255;
		
		while(brightness--) {						
			setGreenLED(brightness);
			_delay_ms( 1000/255);			// Whole sequence will take about 1 sec
		}
		
		
		// We end with brightness=0 so LED is off.	
		
		disableButton();		// Disable pull up to avoid running the battery down. 
	
		// Do not enable interrupt on button pin change - we will require a charger state change to wake up
		// Since the interrupt is not enabled, the pin will be disconnected during sleep so any floating
		// on it will not waste power.
	
		setSpeedStepDefaults();		// Use lockout mode to reset the speed steps to defaults
	
	} else {
	
		// Leave pull-up enabled
	
		PCMSK = _BV(BUTTON_INT);				// Enable interrupt on button pin so we wake on a press
	
	}
			
	
	PCMSK |= _BV(CIP_INT);	// Enable interrupt on change in state-of-charge pin no matter what
		
	GIMSK |= _BV(PCIE);		// Enable pin change interrupt vector. Activates INTs on CIP always and on button only if we are not in stuck button mode.
			
	// Clear pending interrupt flags. This way we will only get an interrupt if something changes
	// after we read it. There is a race condition where something could change between the flag clear and the
	// reads below, so code should be able to deal with possible redundant interrupt and worst case
	// is that we get woken up an extra time and go back to sleep.	
	
	GIFR = _BV(PCIF);						// Clear interrupt flag so we will interrupt on any change after now...
	
	// Note that here we assume that CIP will always go active and wake us whenever the charger is connected, even if the battery is full.
	// This is empirically found to be true. This is handy because there is no good way for us to interrupt on Vcc changes.	
																		
	if ( !CIP_STATE_ACTIVE() && !(readVccVoltage()>=CHARGER_VOLTAGE_THRESHOLD) ) {			// Check if conditions are ALREADY true since we only wake on change....
			
		// Ok, it is bedtime!
		
		set_sleep_mode( SLEEP_MODE_PWR_DOWN );  // Go into deep sleep where only a pin change can wake us.. uses only ~0.1uA!
					
		// GOOD NIGHT!		
		
		// This code disables the Watchdog. Note that we can not use the library wdt_disable() becuase it has a bug
		// that causes intermittent unwanted resets.
		
		// Note interrupts are already clear when we get here, otherwise we would need to worry about getting interrupted between the two following lines

		wdt_disable();
		WDT_off();
		
		sleep_enable();							// "To enter any of the three sleep modes, the SE bit in MCUCR must be written to logic one and a SLEEP instruction must be executed."				
		sei();                                  // Enable global interrupts. "When using the SEI instruction to enable interrupts, the instruction following SEI will be executed before any pending interrupts."		
		sleep_cpu();							// This must come right after the sei() to avoid race condition

		// GOOD MORNING!
		// If we get here, then a button push or change in charger status woke s up....
			
		sleep_disable();						// "To avoid the MCU entering the sleep mode unless it is the programmer's purpose, it is recommended to write the Sleep Enable (SE) bit to one just before the execution of the SLEEP instruction and to clear it immediately after waking up."
		
		cli();									// We are awake now, and do don't care about interrupts anymore (out interrupt routines don't do anything anyway)
				
		wdt_enable( WDTO_8S );			// Re-enable watchdog on wake Give ourselves 8 seconds before reboot
	}
			
	// Ok, now we are running!!!
		
	currentSpeedStep = 0;				// What motor speed setting are we currently on? start operation at OFF. 
				
	while (1)	{	
				
		// This main loop runs for as long as the motor is on. 
		// It can be terminated by battery charger change of state, low battery detection, button press back to 0 speed, or long button press
		// All these changes terminate the loop in a reboot. 

		uint8_t vccx10 = readVccVoltage();		// Snapshot of current voltage level
				
		#ifdef CALIBRATION
		
			// In calibration mode, we receive commands though the power jack so all charging functions are suppressed. 
			readCommand();
		
		#else
		
				
			if ( vccx10 >= CHARGER_VOLTAGE_THRESHOLD ) {			// We are either getting data or a charger is connected
												
				motorOff();								// Always turn off motor when charger connected
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

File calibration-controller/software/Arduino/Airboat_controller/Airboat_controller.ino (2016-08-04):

#include <LiquidCrystal.h>

//Sample using LiquidCrystal library
#include <LiquidCrystal.h>
#include <util\delay.h>
/*******************************************************

This program will test the LCD panel and the buttons
Mark Bramwell, July 2010

********************************************************/

#define JACK_PIN 0

// select the pins used on the LCD panel
LiquidCrystal lcd(8, 9, 4, 5, 6, 7);

// define some values used by the panel and buttons
#define btnRIGHT  0
#define btnUP     1
#define btnDOWN   2
#define btnLEFT   3
#define btnSELECT 4
#define btnNONE   5

#define KEY_DEBOUNCE_MS 30L      // How long we need to see the same Reading for before we accept it


// read the buttons
int read_LCD_buttons()
{
  
 int adc_key_in  =analogRead(0);        // Start from scratch

 // my buttons when read are centered at these valies: 0, 144, 329, 504, 741
 // we add approx 50 to those values and check to see if we are close
  
 // For V1.1 us this threshold
 
 /*
 if (adc_key_in < 50)   return btnRIGHT;  
 if (adc_key_in < 250)  return btnUP; 
 if (adc_key_in < 450)  return btnDOWN; 
 if (adc_key_in < 650)  return btnLEFT; 
 if (adc_key_in < 850)  return btnSELECT;  
*/
 // For V1.0 comment the other threshold and use the one below:

 if (adc_key_in < 50)   return btnRIGHT;  
 if (adc_key_in < 195)  return btnUP; 
 if (adc_key_in < 380)  return btnDOWN; 
 if (adc_key_in < 520)  return btnLEFT; 
 if (adc_key_in < 790)  return btnSELECT;   

 return btnNONE;  // when all others fail, return this...
}

// Call this diagnostic from loop() to check that the values are right.

void printKey() {
      lcd.clear();
      lcd.print( analogRead(0) );
      delay(100);
      return;
}

char buff[10];

#define MODE_MOTOR 1
#define MODE_LED 2

uint8_t mode=MODE_MOTOR;    

#define MAX_DUTY 255
uint8_t duty = 50;

#define MAX_TOP 255
uint8_t top  = 200;

#define MAX_PRESCALE 7    // This is just so the computerd top will always fit into a uint16
uint8_t prescale=1;

uint8_t green = 0;

uint8_t red=0;

// Refresh the Screen

void refreshLabels() {
  
 lcd.setCursor(0,0);
 
 if (mode==MODE_MOTOR) {
   lcd.print("   Duty    Top  "); // print a simple message
   
 } else if (mode==MODE_LED) {
   lcd.print("    Red  Green  "); // print a simple message
 }
 
}
  
// left padded, 5 digit string

void digitstring( uint16_t x ) {
  
  uint8_t place = 5;
   
  while (place--) {
    
    uint16_t next = x/10;
    
    buff[place] = (x-(next*10)) + '0';
    
    if (!next) {
      
      while (place--) {
        
        buff[place] = ' ';
        
      }
      
      return;
      
    }
    
    x=next;
    
  }
    
  
}

void refreshTop() {
  
     lcd.setCursor(9,1);  
     digitstring( ((unsigned) top ) * ( 1<<(prescale-1) ) );  
     lcd.print(buff); 

}

void refreshDuty() {

     lcd.setCursor(2,1);
     digitstring(duty);      
     lcd.print(buff); 
  
}

void refreshRed() {
     lcd.setCursor(2,1);   
     digitstring(red); 
     lcd.print(buff);   
}

void refreshGreen() {
     lcd.setCursor(9,1);  
     digitstring(green);
     lcd.print(buff);      
}

void refreshValues() {

 if (mode==MODE_MOTOR) {
    
     refreshDuty();
     refreshTop();
  
  } else if (mode==MODE_LED) {
    
     refreshRed();  
     refreshGreen();
  }
}

void refresh() {
  refreshLabels();
  refreshValues();
}


void showKeyPress() {
  
 uint16_t a = analogRead(0);
  
 lcd.setCursor(2,1); 
  
 digitstring(a); 
 lcd.print(buff); 
  
  _delay_ms(1000);
  
 return;
}  


// We are using an PNP, so driving the gate low will energise the plug

#define ON()    digitalWrite(JACK_PIN,LOW)
#define OFF()   digitalWrite(JACK_PIN,HIGH)


void setupJack() {

  // Pin 8 connected to PNP transistor that controls power to the plug  
  pinMode( JACK_PIN , OUTPUT );
  OFF();

}


// Returns 0 or 1

uint8_t parity( uint8_t b ) {

  uint8_t p=0;

  while (b) {

    if (b & 1) p^=1;
    b >>=1;
  }

  return(p);
}

// Commands defined in the firmware source

int sendCommand( uint8_t command, uint8_t a, uint8_t b ) {

  // Sanity check field lengths

  if (command > 0b111 )   return(1);
  if (a       > 0b1111 )  return(2);

  // Did you know that the xor of two bytes together has the same partity of the two bytes seporately?

  unsigned packet = ( command << 13U ) | ( a << 9 ) | ( b << 1 ) | parity( command ^ a ^ b );
   
    
  unsigned  bitmask = 1U<<15;

  // Create the top of the first sync pulse. 
  // This has to be long enough to get the recievers attention and have them ready to see the 1st sync fall

  ON();
  _delay_us(10000);   // With the 2000us below we wil get a full 22ms before the first drop
                      // Since each main loop on the unit takes ~13ms, we need this to be long enough to 
                      // get the data decoders attention and have it ready and waiting for the falling edge, but
                      // Anything more than 16ms will be read as charging
  
  while (bitmask) {

    // Sync pulse       
    ON();
    _delay_us(3000);  
    OFF();              // We sync to this trailing edge
                        // Trailing is better becase the CIP responds almost instantly 
                        // when the voltage drops.

    _delay_us(1000);     // The trigger valley.                     

   // Next comes the actual data bit window. It must be 2000us long.
   // The first 1ms is rise time (if the bit is 1), then the next 1ms is sample window.
   // Sample targets the center of the window, 2500us after the falling sync edge (1500us after the rise)

    if (packet & bitmask) {

      // Do nothing on most bits - the next sync pulse will be sampled and read as high. Saves 2ms on 1 bits.

      if (bitmask==1) {       // Are we on the final bit?

          ON();
          _delay_us(3000);    // we have to send ourselves
          OFF();
      
      }
            
    } else {

      // stay off for 3000us. 
      _delay_us(3000);

    }
    
    bitmask >>= 1;
    
  }

  // we actually do not need to do anything here. we are always guaranteed to be low when we get here.

   return(0);
  
}

void setup()
{
  setupJack();
  lcd.begin(16, 2);              // start the library
  
  lcd.clear();    
  lcd.noCursor();
  refresh();    
  
}


#define INITIAL_DELAY 500    // Delay between 1st and 2nd repeat of a keypress

uint16_t keyDelay=INITIAL_DELAY;      // start with 1 second delay btween ticks

unsigned long nextKeyTime=0;        // Next time key will repeat

uint8_t lastkey=0;

long t=0;

// Only send updates at most once per second to keep things responsive
// since a send takes like 100ms

#define CHANGE_GREEN    _BV(0)
#define CHANGE_RED      _BV(1)
#define CHANGE_DUTY     _BV(2)
#define CHANGE_TOP      _BV(3)

uint8_t changeFlags=0;

#define SEND_TIMEOUT_MS 500

unsigned long nextSend=0;
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

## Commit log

2016-06-12 PCB Version 0.1
2016-06-14 Switched to round holes for jack because Othermill cant do slots
2016-06-14 First compilable version - just tests timer
2016-06-14 Move motor control to better PWM pin, loose some vias and backside jack connections
    [main.c]
2016-06-15 Added LED current limit resistor. Firmware working with PWM motor and LEDs.
2016-06-16 New board with better decoupling for AVR and fewer vias
2016-06-16 Even more pcb trace cleanup
2016-06-16 PCB really good now
2016-06-17 LEDs and Vcc measurement working
2016-06-19 Straighten backside traces for easier jumpers
2016-06-19 Switch to SIOC 209mm 'cause thats what I got
2016-06-19 Rework traces for 1/64th clearance
    Conical bit not working, so switching to 1/64th end mill.
2016-06-20 Sendout to PCBWAY candidate 1
    Completely removed provision for detecting end-of-charge to eliminate
    chance of jack shortout
2016-06-20 Airboat 0.3 as ordered
    Added some silk to make assembly easier.
2016-06-21 Added 1- and 2-sided button board designs with associated components and patterns
    2-side board as ordered
2016-06-21 Indicate transit lockout activated with fade-to-black rather than flash. Fix issue #5.
    Issue #5 turned out to be just that the line that turned off the led was
    in slightly the wrong place.
    [main.c]
2016-06-21 Clean working without voltage compensation
2016-06-27 Updated BOM
    Pulled BOM file in from Digikey for easier sharing
    [AIRBOAT Digikey BOM.csv, Vibe_BOM - Sheet1.csv, Vibe_BOM.xlsx]
2016-06-29 Include 3D models for LED and Jack
    [Bicolor LED.step, mj1-2503a.stp]
2016-07-14 First steps to calibration controller with docs. Also clock speed fuses now 128Khz.
2016-07-18 Good layout with SMD power jack cures #7 #12 #8
    Total relayout and updated schematic. Added diode to EOC detection.
    Added fuse (but no zener). Switched to SMD power jack rather than TH
    audio jack. Lots of vias, not practically millable anymore.
2016-07-18 Replaces the protection diode with an array
    This should be easier to assemble and slightly protects the MCU from
    reverse polartity and protects the battery from a short on the power
    jack.
2016-07-25 End-of-charge working
    Green LED now on solid when charger connected but battery full.
2016-07-25 Led Resistor changed to 200 ohm
    ...to allow programming with normal STK600
2016-07-26 End of charge detection working, but needs cleanup and testing
2016-07-26 Larger button board 14mmx4.5mm with correct larger size pads
2016-07-26 Added 3D model of button
    [TL3302AFXXXQG.stp]
2016-07-26 Combined boards with V-Grove
2016-07-27 Combine main board and button board into single schematic
    Also clean out old button board & other legacy files
2016-07-27 Clean up part names and data sheet URLs in schematic
2016-07-27 Remove Motor Flywheel Diode
2016-07-27 Clean libraries, clean up silk on L1
    Renamed component lib from vibe->airboard, removed unused components.
    Make the silk fir L1 fit inside the footprint and indicate which way the
    LED points.
2016-07-27 Updated BOM and BOM notes
    Removed the motor diode, updated substitution info to notes.
    [AIRBOAT Digikey BOM.csv]
2016-07-27 Updated board notes file
    Tried to add info about the combined boards and jumper wires, but yuck.
2016-07-27 Removed all programming jigs and testing info. Will re-add and update later.
    [vibe_v2_programming_jig_guide_ramps.stl]
2016-07-27 Clean up the silk on the power jack so it doesn't extend off the board.
2016-07-27 Added Fudicials to schematic, and a box with legend for the button subassembly.
2016-07-27 Relate Fusdicials from schematic to layout
2016-07-27 Make schematic look nice as PDF. Clarify shrink/swell in notes.
2016-07-27 Update exported digikey BOM to remove reference to now-deleted C1
    [AIRBOAT Digikey BOM.csv]
2016-07-29 Able to receive a data byte over the charging port and blink it on the LED.
    Also changed all references to the white led to green to match the
    hardware, and added a setOrgangeLed() to turn on both LEDs to make
    orangefor button feedback.
2016-07-29 Color correction to make the orange a bit ornagier
    [main.c]
2016-07-30 Reading data from power jack working nice and smooth!
    Still a race condition to find EOC when CIP is active - but for
    tomorrow!
2016-08-01 Removed ADC prescaler for 128khz. No controller, but charging code good.
2016-08-01 Moved speed settings from FLASH into RAM so we can change them with calibration
2016-08-02 Power port communication working.
    Simple Arduino demo can turn on the LEDs via the power port.
2016-08-02 Data communication works and command implemented. Needs cleanup.
    Need a better keybounce routine. There is a something unexpected still
    happening when red LED command transisions form 50's to 70's.
2016-08-02 Button debounce perfect!
2016-08-03 Calibration Controller complete and nice and smooth
2016-08-03 Update calibration docs
2016-08-04 Disable calibration feature
2016-08-04 Change button-push LED feedback to green
2016-08-04 Fixed tool url and case on signals image
2016-08-04 Updated default speed step settings
    Empirical values as per calibration controller testing in the office.
2016-08-04 Switch prescaler calculationt to output bit index rather than value. Added USBTiny examples.
2016-08-04 Added fuses to source file so they can be included in output ELF
